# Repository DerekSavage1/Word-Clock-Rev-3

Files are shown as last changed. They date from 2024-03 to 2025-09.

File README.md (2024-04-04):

# Word Clock

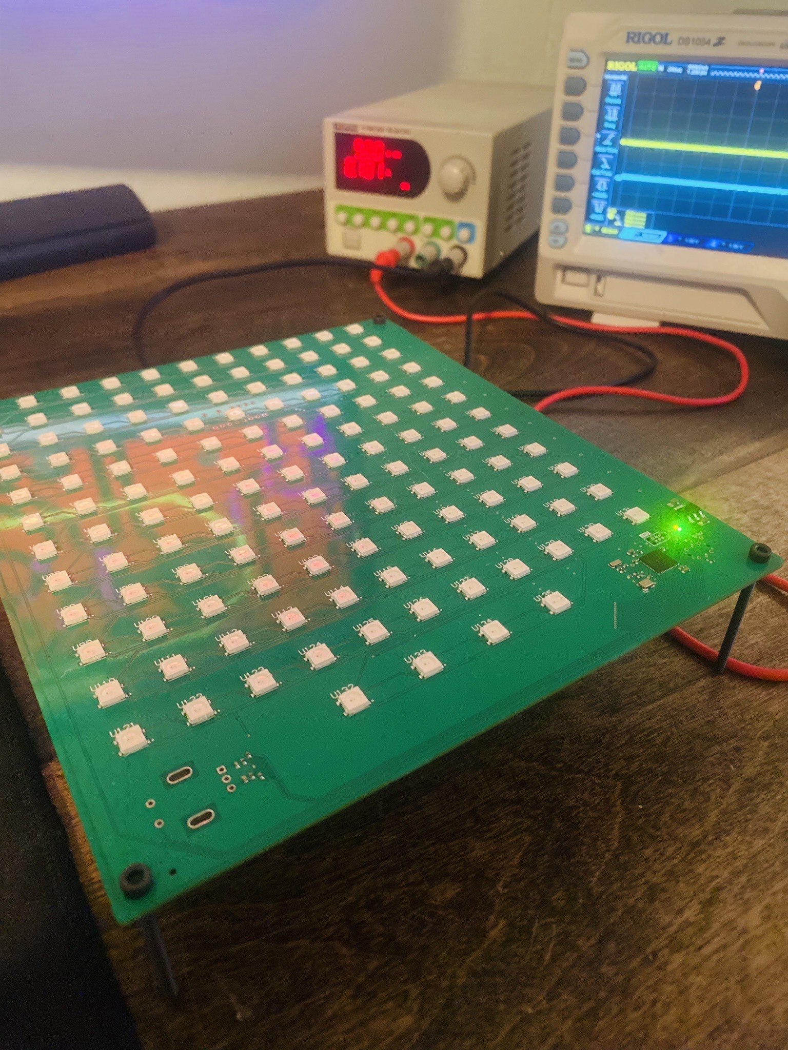
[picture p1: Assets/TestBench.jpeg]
Test Bench


## Overview

This project uses a matrix of indiviually controllable letters to spell out time. You can set a custom birthday and anniversary and an entire row of 11 letters is left free for customization. Setting the time, date, color, brightness, and even anniversary / birthdays can be done from the back of the device. Unless you are adding a custom name, no hardcoding is necessary.

## Technical Details

### Specs
- **Display Technology**: Individually addressable WS2812B RGB LEDs illuminate each letter. 
- **Microcontroller**: Driven by the high-performance STM32F4 Microcontroller.
- **Real-Time Clock (RTC)**: The RTC is kept on the STM32 with an external 32.768 kHz crystal for accuracy.
- **User Interface**: A 4-digit 7-segment display coupled with a pushable rotary encoder allows adjustments for time, color, date, etc.
- **Power Source**: Powered through a USB-C cable as this is my favorite cable.
- **Enclosure**: Designed to snugly fit a 9x9 shadow box from Michaels.

### Tools
- **Software Environment**: STM32 Cube IDE
- **Hardware Environment**: Altium Designer

## Assembly and Setup

### Building the Clock

1. **Manufacture the Clock**: You'll find the Gerber, BOM, and CPL files for sending to your preferred PCB manufacturer.
2. **Microcontroller Programming**: A 6 pin J link adapter is necessary for programming the microcontroller. Refer to the SWD on the board for the programming interface.
3. **3D Printing**: Certain components are to be 3D printed and assembled using M6 nuts and bolts.
4. **Letter Mask**: Included is a vector file for the mask — these letters cater to my specific requirements, yet the design permits custom text display through full customization of a row of letters. This design can be sent to a company specializing in making vinyl stickers. This sticker should be applied from the inside of the glass so consider how you will have to (or not have to) mirror your file before sending. This mask can then be applied carefully so each letter is in front of it's respective LED.
5. **Film**: Adding a one-way film to the glass front makes the unlit letters harder to see.
6. **Prepare Back Panel**: To accommodate the 7 segment display, the rotary encoder, and the USB-C, the back panel requires laser cutting. I will provide the SVG file used for this purpose shortly.
7. **Assemble**: Commence with a 9x9 diffusion paper layer, followed by the PCB with letters facing the glass, and finally secure the back panel in place.

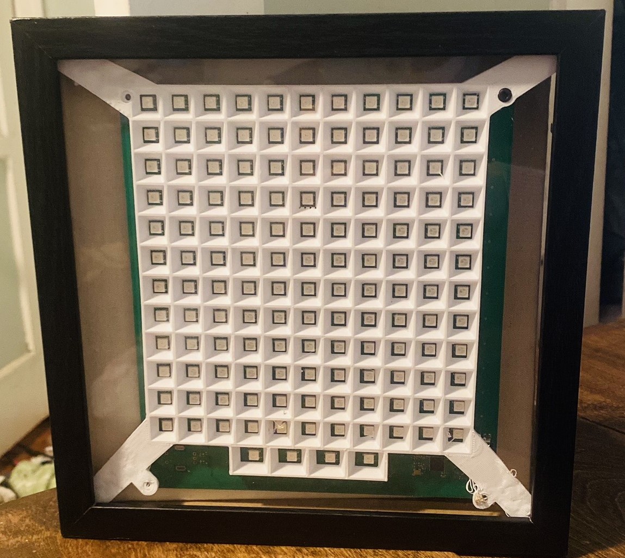
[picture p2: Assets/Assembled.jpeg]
Assembled Clock


### Operation

- **Setting the Time**: Utilize the dial to cycle through hours and minutes, pressing it to alternate between selections. The current setting is displayed on the 7-segment display.
- **Powering the Clock**: Simply connect the clock to a power outlet using a USB-C cable, and it will start showcasing the current time.

## Contact

Should you have any inquiries, feel free to contact me at d.savag1@gmail.com.

This project is duly licensed under GNU General Public License v3.0 to allow both personal and commercial use, provided due attribution is made.

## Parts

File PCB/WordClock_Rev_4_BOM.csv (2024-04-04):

Comment | Description | Designator | Footprint | LibRef | Quantity | LCSC Part #
Capacitor 100nF +/-20% 25V 0402 | Chip Capacitor, 100nF +/-20%, 25V, 0402, Thickness 0.6 mm | C1, C2, C20, C21, C22, C23, C24, C25, C26, C27, C28, C29, C30, C31, C32, C33, C34, C35, C36, C37, C38, C39, C40, C41, C42, C43, C44, C45, C46, C47, C48, C49, C50, C51, C52, C53, C54, C55, C56, C57, C58, C59, C60, C61, C62, C63, C64, C65, C66, C67, C68, C69, C70, C71, C72, C73, C74, C75, C76, C77, C78, C79, C80, C81, C82, C83, C84, C85, C86, C87, C88, C89, C90, C91, C92, C93, C94, C95, C96, C97, C98, C99, C100, C101, C102, C103, C104, C105, C106, C107, C108, C109, C110, C111, C112, C113, C114, C115, C116, C117, C118, C119, C120, C121, C122, C123, C124, C125, C126, C127, C128, C129, C130, C131, C132, C133, C134, C135, C136, C137, C138, C139, C140, C141, C142, C143, C144, C145, C146, C147, C148, C149, C150, C151, C152, C153, C154, C155, C156, C157, C158, C159 | CAPC0402(1005)60_L | CMP-001-00065-4 | 142 | C1525
22u | Capacitor SMD 0805 | C3, C4 | CAP_0805 | CAP_0805 | 2 | C45783
10n | Capacitor SMD 0402 | C5, C6, C19 | CAP_0402 | CAP_0402 | 3 | C15195
10p | Capacitor SMD 0402 | C7, C8, C9, C10 | CAP_0402 | CAP_0402 | 4 | C32949
2u2 | Capacitor SMD 0603 | C11, C13 | CAP_0603 | CAP_0603 | 2 | C1604
100n | Capacitor SMD 0402 | C12, C14, C15, C16, C17, C18 | CAP_0402 | CAP_0402 | 6 | C1525
GREEN | LED 0402 GREEN SMD | D1 | LED_0402_GREEN | LED_0402_GREEN | 1 | C434449
C316041 | Diode TVS / ESD 0402 | D2 | D_0402 | D_TVS_0402 | 1 | C316041
RED | LED 0402 RED SMD | D3 | LED_0402_RED | LED_0402_RED | 1 | C965790
1k | Resistor SMD 0402 | R1, R8 | RES_0402 | RES_0402 | 2 | C11702
10k | Resistor SMD 0402 | R2, R3, R4, R5, R9, R12 | RES_0402 | RES_0402 | 6 | C25744
5k1 | Resistor SMD 0402 | R6, R7 | RES_0402 | RES_0402 | 2 | C25905
0R | Resistor SMD 0402 | R10, R11 | RES_0402 | RES_0402 | 2 | C17168
WS2812B | Intelligent Control LED Integrated Light Source, 3.5 to 5.3 V, -25 to 80 degC, 4-Pin SMD, RoHS, Bulk | U0, U1, U2, U3, U4, U5, U6, U7, U8, U9, U10, U11, U12, U13, U14, U15, U16, U17, U18, U19, U20, U21, U22, U23, U24, U25, U26, U27, U28, U29, U30, U31, U32, U33, U34, U35, U36, U37, U38, U39, U40, U41, U42, U43, U44, U45, U46, U47, U48, U49, U50, U51, U52, U53, U54, U55, U56, U57, U58, U59, U60, U61, U62, U63, U64, U65, U66, U67, U68, U69, U70, U71, U72, U73, U74, U75, U76, U77, U78, U79, U80, U81, U82, U83, U84, U85, U86, U87, U88, U89, U90, U91, U92, U93, U94, U95, U96, U97, U98, U99, U100, U101, U102, U103, U104, U105, U106, U107, U108, U109, U110, U111, U112, U113, U114, U115, U116, U117, U118, U119, U120, U121, U122, U123, U124, U125, U126, U127, U128, U129, U130, U131, U132, U133, U134, U135, U136, U137, U138, U139, U140, U141 | ADAI-WS2812B_V | CMP-007-00035-2 | 142 | C2843785
AMS1117-3.3 | LDO Voltage Regulators 1A, 3.3V | U142 | FP-AMS1117-IPC_C | CMP-209535-000001-1 | 1 | C6186
STM32F411CEU6 | ARM Cortex-M4 32-bit MCU+FPU, 512 KB Flash, 128 KB RAM, 36 I/Os, 48-Pin UFQFPN, -40 to 85 degC, Tray | U143 | STM-UFQFPN48_L | CMP-0243-00165-1 | 1 | C60420
32MHz768 | Crystal SMD 3215 | X1 | XTAL_3215-2 | XTAL_3215 | 1 | C620155
24MHz | C7294565 | X2 | XTAL_3225 | TSX-3225_24.0000MF15X-AC | 1 | C7294565

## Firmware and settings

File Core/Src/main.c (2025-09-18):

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
/* Includes ------------------------------------------------------------------*/
#include "main.h"

/* USER CODE BEGIN Includes */
#include <stdint.h>
#include <math.h>
#include <numeric_display.h>
#include <string.h>
#include <stdio.h>
#include <stdbool.h>
#include <string.h>
#include "color.h"
#include "time_display.h"
#include "flicker.h"
#include "button.h"
#include "menu.h"
#include "settings.h"
#include "rainbow.h"
#include "twinkle.h"
#include "blink.h"
#include "constant.h"
/* USER CODE END Includes */

RTC_HandleTypeDef hrtc;

TIM_HandleTypeDef htim1;
TIM_HandleTypeDef htim3;
DMA_HandleTypeDef hdma_tim1_ch1;

/* USER CODE BEGIN PV */

RTC_TimeTypeDef sTime;
RTC_DateTypeDef sDate = {0, 0, 0, 24};
RTC_DateTypeDef aDate = {0, 0, 0, 99};
RTC_DateTypeDef bDate = {0, 0, 0, 99};

uint32_t lastTick = 0;

/* USER CODE END PV */

void SystemClock_Config(void);
static void MX_GPIO_Init(void);
static void MX_DMA_Init(void);
static void MX_TIM1_Init(void);
static void MX_TIM3_Init(void);
static void MX_RTC_Init(void);
/* USER CODE BEGIN PFP */
void HAL_GPIO_EXTI_Callback(uint16_t GPIO_Pin);
/* USER CODE END PFP */

/**
  * @brief  The application entry point.
  * @retval int
  */
int main(void)
{

  /* MCU Configuration--------------------------------------------------------*/

  /* Reset of all peripherals, Initializes the Flash interface and the Systick. */
  HAL_Init();

  /* Configure the system clock */
  SystemClock_Config();

  /* Initialize all configured peripherals */
  MX_GPIO_Init();
  MX_DMA_Init();
  MX_TIM1_Init();
  MX_TIM3_Init();
  MX_RTC_Init();
  /* USER CODE BEGIN 2 */
  HAL_TIM_Encoder_Start(&htim3, TIM_CHANNEL_ALL); // Start the encoder interface
  setColorWithPreset(0);
  /* USER CODE END 2 */

  /* Infinite loop */
  /* USER CODE BEGIN WHILE */


  while (1)
  {
    /* USER CODE END WHILE */

    /* USER CODE BEGIN 3 */

	if(checkButtonPress()){
		switchState();
	}

	// get time and get date must both be called
	HAL_RTC_GetTime(&hrtc, &sTime, RTC_FORMAT_BIN);
	HAL_RTC_GetDate(&hrtc, &sDate, RTC_FORMAT_BIN);

	configureSettings();


	Segment_Display(getDisplayString());



	flicker(sTime);
	rainbow(sTime);
	blink();
	constant();
	updateDisplayColor();

	sendDisplayToDMA();



  }
  /* USER CODE END 3 */
}

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


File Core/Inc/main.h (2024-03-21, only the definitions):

#define SEG_B_K_Pin GPIO_PIN_0
#define SEG_B_K_GPIO_Port GPIOA
#define SEG_G_K_Pin GPIO_PIN_1
#define SEG_G_K_GPIO_Port GPIOA
#define SEG_A_K_Pin GPIO_PIN_2
#define SEG_A_K_GPIO_Port GPIOA
#define SEG_C_K_Pin GPIO_PIN_3
#define SEG_C_K_GPIO_Port GPIOA
#define SEG_F_K_Pin GPIO_PIN_4
#define SEG_F_K_GPIO_Port GPIOA
#define DIG_4_A_Pin GPIO_PIN_5
#define DIG_4_A_GPIO_Port GPIOA
#define DP_K_Pin GPIO_PIN_6
#define DP_K_GPIO_Port GPIOA
#define DIG_3_A_Pin GPIO_PIN_7
#define DIG_3_A_GPIO_Port GPIOA
#define SEG_E_K_Pin GPIO_PIN_0
#define SEG_E_K_GPIO_Port GPIOB
#define DEC_A_Pin GPIO_PIN_1
#define DEC_A_GPIO_Port GPIOB
#define SEG_D_K_Pin GPIO_PIN_2
#define SEG_D_K_GPIO_Port GPIOB
#define DIG_2_A_Pin GPIO_PIN_10
#define DIG_2_A_GPIO_Port GPIOB
#define DIG_1_A_Pin GPIO_PIN_12
#define DIG_1_A_GPIO_Port GPIOB
#define BUTTON_Pin GPIO_PIN_15
#define BUTTON_GPIO_Port GPIOB
#define LED_Pin GPIO_PIN_15
#define LED_GPIO_Port GPIOA

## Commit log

2024-01-26 Separate Numeric Display control logic into dedicated driver files
2024-01-26 Added input processing with error indicators and case normalization
    [Numeric_Display.c]
2024-01-26 Refactor: Extract encoder logic from main to dedicated driver files
2024-03-20 modified: .settings/language.settings.xml modified: .settings/stm32cubeide.project.prefs modified: Core/Inc/main.h modified: Core/Inc/stm32f4xx_it.h modified: Core/Src/main.c modified: Core/Src/stm32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
2024-03-20 switched to STM32 native encoder implementation
2024-03-31 flicker effect no longer uses delay
    [WS2812B.c, WS2812B.h, WordClock_Rev_3.ioc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]
2024-04-04 added gitignore
    [WordClock_LED_Display.SchDoc, WordClock_Rev_3.PrjPcb, WordClock_Rev_4_BOM.csv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]
2024-04-06 Fixed bit offset in DMA handling
    [WS2812B.c]
2025-09-18 fixed bug with setting date
    [button.c]

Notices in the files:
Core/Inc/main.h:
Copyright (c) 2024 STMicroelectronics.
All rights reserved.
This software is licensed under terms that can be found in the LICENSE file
